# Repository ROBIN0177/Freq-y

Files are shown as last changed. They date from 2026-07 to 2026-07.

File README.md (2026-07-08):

# Freq-y
## Your Frequency Scanning Companion

I made this project because there isn't a cheap frequency scanner you can rely on. If you've built RF projects before, you know the pain of tracking down a signal leak, figuring out where it's coming from, what frequency it's on, and which device is causing it.

I ran into this myself: my home WiFi was getting choked by an unknown source. Turned out to be my own custom radio bleeding into the band. This scanner also lets you test how much shielding a material actually provides—whether it's a wall, a case, or a Faraday cage. Pinpoint the exact device causing interference easily. (Unlike me. Took 3 days to figure out..)

---

## Pictures




(Mind the hole, it's for a rocker switch I couldn't get a STL of.)





---

## BOM

Full BOM with DigiKey part numbers: see `/BOM/`

---

## File Structure

```
Freq-y/
├── CAD/
│   ├── enclosure_top.stl
│   └── enclosure_bottom.stl
├── PCB/
│   ├── Freq-y_Schem
|   ├── Freq-y_PCB
│   └── Freq-y_Pro
├── GERBER/
│   ├── Freq-y-B_Cu.gbr
│   ├── Freq-y-F_Cu.gbr
│   ├── Freq-y-B_Mask.gbr
│   ├── Freq-y-F_Mask.gbr
│   ├── Freq-y-B_Silkscreen.gbr
│   ├── Freq-y-F_Silkscreen.gbr
│   ├── Freq-y-Edge_Cuts.gbr
│   ├── Freq-y-B_Paste.gbr
│   ├── Freq-y-F_Paste.gbr
│   ├── Freq-y-NPTH.drl
│   ├── Freq-y-PTH.drl
│   └── Freq-y.zip
├── BOM/
│   ├── BOM_DigiKey.csv
│   └── BOM_AUX.csv
├── README.md
├── Journal.md
└── LICENSE
```

---

## Special Thanks

**Hack Club** — I couldn't have made this without it.

## NOTE

RF impedance was calculated to the nearest allowed mm. Any more would have severed and or created problems for other components!!
Range is limited due to it not having exact RF impedance!!

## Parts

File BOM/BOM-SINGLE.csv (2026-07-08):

Item | Description | Qty | Unit Price | Total | Vendor | Notes
 | === AMAZON PARTS (CAD → USD) ===
1 | SPST On/Off Mini Boat Rocker Switch, AC 6A/250V 10A/125V, 2 Solder Lug, 2Pin Toggle, Snap-in, 15 Pcs | 1 | $8.99 CAD → $6.47 USD | $8.99 CAD → $6.47 USD | ZUPAYIPA / Amazon.ca | In Stock
2 | Li-Po Battery Pack 3.7V 1100mAh 603449 with JST Connector | 1 | $17.85 CAD → $12.85 USD | $17.85 CAD → $12.85 USD | A2BATT INC / Amazon.ca | In Stock; verify device polarity before use
3 | Dual Band WiFi Antenna 2.4GHz/5GHz/5.8GHz MIMO, RP-SMA, Short | 1 | $13.99 CAD → $10.07 USD | $13.99 CAD → $10.07 USD | efagur / Amazon.ca | In Stock; for Furrion RV backup camera / router / repeater
4 | 2.8" 240x320 SPI ILI9341 LCD TFT Touch Panel, Serial Port | 1 | $23.23 CAD → $16.73 USD | $23.23 CAD → $16.73 USD | Ninlyier / Amazon.ca | Only 3 left in stock
 | Amazon Parts Subtotal |  | $64.06 CAD | $46.12 USD
 | Amazon Tax + Shipping |  | $9.54 USD | $9.54 USD
 | === OTHER SOURCES (USD) ===
 | PCB Fabrication (PCBWay) |  |  | $59.4 USD | PCB Vendor
 | Digi-Key Components |  |  | $45.32 USD | Digi-Key
 | === GRAND TOTAL (USD) === |  |  | $157.70999999999998 USD |  | Includes Amazon tax/shipping converted to USD

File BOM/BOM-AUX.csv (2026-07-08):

Item | Description | Qty | Unit Price | Total | Vendor | Notes
1 | SPST On/Off Mini Boat Rocker Switch, AC 6A/250V 10A/125V, 2 Solder Lug, 2Pin Toggle, Snap-in, 15 Pcs | 1 | 8.99 | 8.99 | ZUPAYIPA / Amazon.ca | In Stock
2 | Li-Po Battery Pack 3.7V 1100mAh 603449 with JST Connector | 1 | 17.85 | 17.85 | A2BATT INC / Amazon.ca | In Stock; verify device polarity before use
3 | Dual Band WiFi Antenna 2.4GHz/5GHz/5.8GHz MIMO, RP-SMA, Short | 1 | 13.99 | 13.99 | efagur / Amazon.ca | In Stock; for Furrion RV backup camera / router / repeater
4 | 2.8" 240x320 SPI ILI9341 LCD TFT Touch Panel, Serial Port | 1 | 23.23 | 23.23 | Ninlyier / Amazon.ca | Only 3 left in stock

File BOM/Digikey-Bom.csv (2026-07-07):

Index | Quantity | Part Number | Manufacturer Part Number | Description | Customer Reference | Available | Backorder | Unit Price | Extended Price CAD
1 | 10 | 1292-0603X106M100CT-ND | 0603X106M100CT | CAP CER 10UF 10V X5R 0603 |  | 10 | 0 | 0.06500 | 0.65
2 | 1 | 478-KGM15BR51A475MTCT-ND | 0603ZD475MAT2A | CAP CER 4.7?F 10V X5R 0603 |  | 1 | 0 | 1.04000 | 1.04
3 | 12 | 732-8013-1-ND | 885012206095 | CAP CER 0.1UF 50V X7R 0603 |  | 12 | 0 | 0.04500 | 0.54
4 | 4 | 490-1411-1-ND | GRM1885C1H220JA01D | CAP CER 22PF 50V C0G/NP0 0603 |  | 4 | 0 | 0.15000 | 0.60
5 | 4 | 490-16342-1-ND | GRM1885C1H1R0WA01D | CAP CER 1PF 50V C0G/NP0 0603 |  | 4 | 0 | 0.30000 | 1.20
6 | 1 | 732-5355-ND | 61301421021 | CONN HEADER R/A 14POS 2.54MM |  | 1 | 0 | 1.50000 | 1.50
7 | 1 | 490-7784-1-ND | LQM2MPN1R0NG0L | FIXED IND 1UH 1.4A 107 MOHM SMD |  | 1 | 0 | 0.26000 | 0.26
8 | 1 | 490-LQP03TG3N9B02DCT-ND | LQP03TG3N9B02D | FIXED IND 3.9NH 350MA 350 MOHM |  | 1 | 0 | 0.15000 | 0.15
9 | 1 | 2073-USB4105-GF-ACT-ND | USB4105-GF-A | CONN RCP USB2.0 TYP C 16P SMD RA |  | 1 | 0 | 1.20000 | 1.20
10 | 1 | 311-5.10KHRCT-ND | RC0603FR-075K1L | RES 5.1K OHM 1% 1/10W 0603 |  | 1 | 0 | 0.16000 | 0.16
11 | 1 | 311-2.00KHRCT-ND | RC0603FR-072KL | RES 2K OHM 1% 1/10W 0603 |  | 1 | 0 | 0.16000 | 0.16
12 | 1 | 311-10.0KHRCT-ND | RC0603FR-0710KL | RES 10K OHM 1% 1/10W 0603 |  | 1 | 0 | 0.16000 | 0.16
13 | 1 | 311-22.0KHRCT-ND | RC0603FR-0722KL | RES 22K OHM 1% 1/10W 0603 |  | 1 | 0 | 0.16000 | 0.16
14 | 1 | 311-56KHRCT-ND | RC0603FR-0756KL | RES 56K OHM 1% 1/10W 0603 |  | 1 | 0 | 0.16000 | 0.16
15 | 2 | 311-4.70KHRCT-ND | RC0603FR-074K7L | RES 4.7K OHM 1% 1/10W 0603 |  | 2 | 0 | 0.16000 | 0.32
16 | 1 | EG1903-ND | EG1218 | SWITCH SLIDE SPDT 200MA 30V |  | 1 | 0 | 1.08000 | 1.08
17 | 1 | 296-35718-1-ND | CC1101RGPR | IC RF TXRX ISM<1GHZ 20QFN |  | 1 | 0 | 6.46000 | 6.46
18 | 1 | 5407-ESP32-S3-MINI-1-N8CT-ND | ESP32-S3-MINI-1-N8 | RF TXRX MODULE BT PCB TRACE SMD |  | 1 | 0 | 8.68000 | 8.68
19 | 1 | MAX17048G+T10CT-ND | MAX17048G+T10 | IC BATT MON LI-ION 1CELL 8TDFN |  | 1 | 0 | 6.75000 | 6.75
20 | 1 | MCP73831T-2ACI/OTCT-ND | MCP73831T-2ACI/OT | IC BATT CNTL LI-ION 1CEL SOT23-5 |  | 1 | 0 | 1.22000 | 1.22
21 | 2 | 535-9134-1-ND | ABM8-16.000MHZ-B2-T | CRYSTAL 16.0000MHZ 18PF SMD |  | 2 | 0 | 0.83000 | 1.66
22 | 2 | 644-STDCSQ1-26MCT-ND | STDCSQ1-26M | CRYSTAL 26.0000MHZ 10PF SMD |  | 2 | 0 | 1.44000 | 2.88
23 | 1 | 4823-NRF24L01P-R7CT-ND | NRF24L01P-R7 | IC RF TXRX ISM>1GHZ 20QFN |  | 1 | 0 | 6.81000 | 6.81
24 | 2 | 357-CON-SMA-EDGE-ND | CON-SMA-EDGE | CIRCULAR COAXIAL SUB-MINITURE |  | 2 | 0 | 3.35000 | 6.70
25 | 1 | 296-12719-1-ND | TPS62203DBVT | IC REG BUCK 3.3V 300MA SOT23-5 |  | 1 | 0 | 2.88000 | 2.88
26 | 2 | 490-14914-1-ND | LQP03TQ12NH02D | FIXED IND 12NH 250MA 690 MOHM |  | 2 | 0 | 0.16000 | 0.32
27 | 2 | 490-6716-1-ND | LQP03TN1N2B02D | FIXED IND 1.2NH 750MA 100 MOHM |  | 2 | 0 | 0.15000 | 0.30

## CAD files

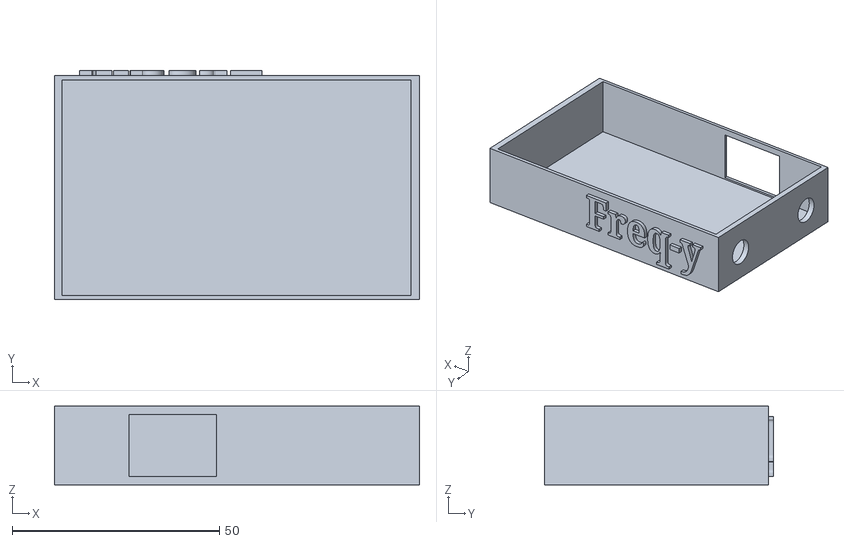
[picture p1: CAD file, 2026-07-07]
CAD/enclosure-bottom.stl
88.0 x 55.2 x 19.0

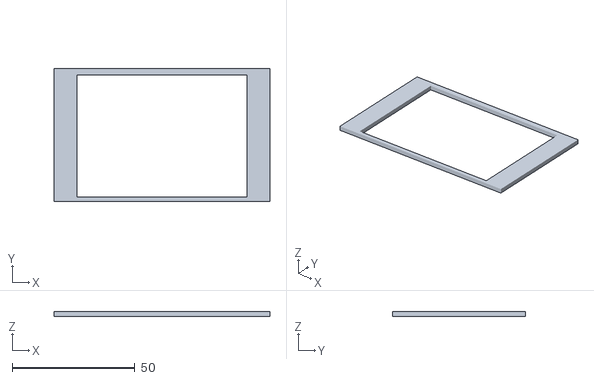
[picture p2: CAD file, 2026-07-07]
CAD/enclosure-top.stl
88.0 x 54.0 x 2.00

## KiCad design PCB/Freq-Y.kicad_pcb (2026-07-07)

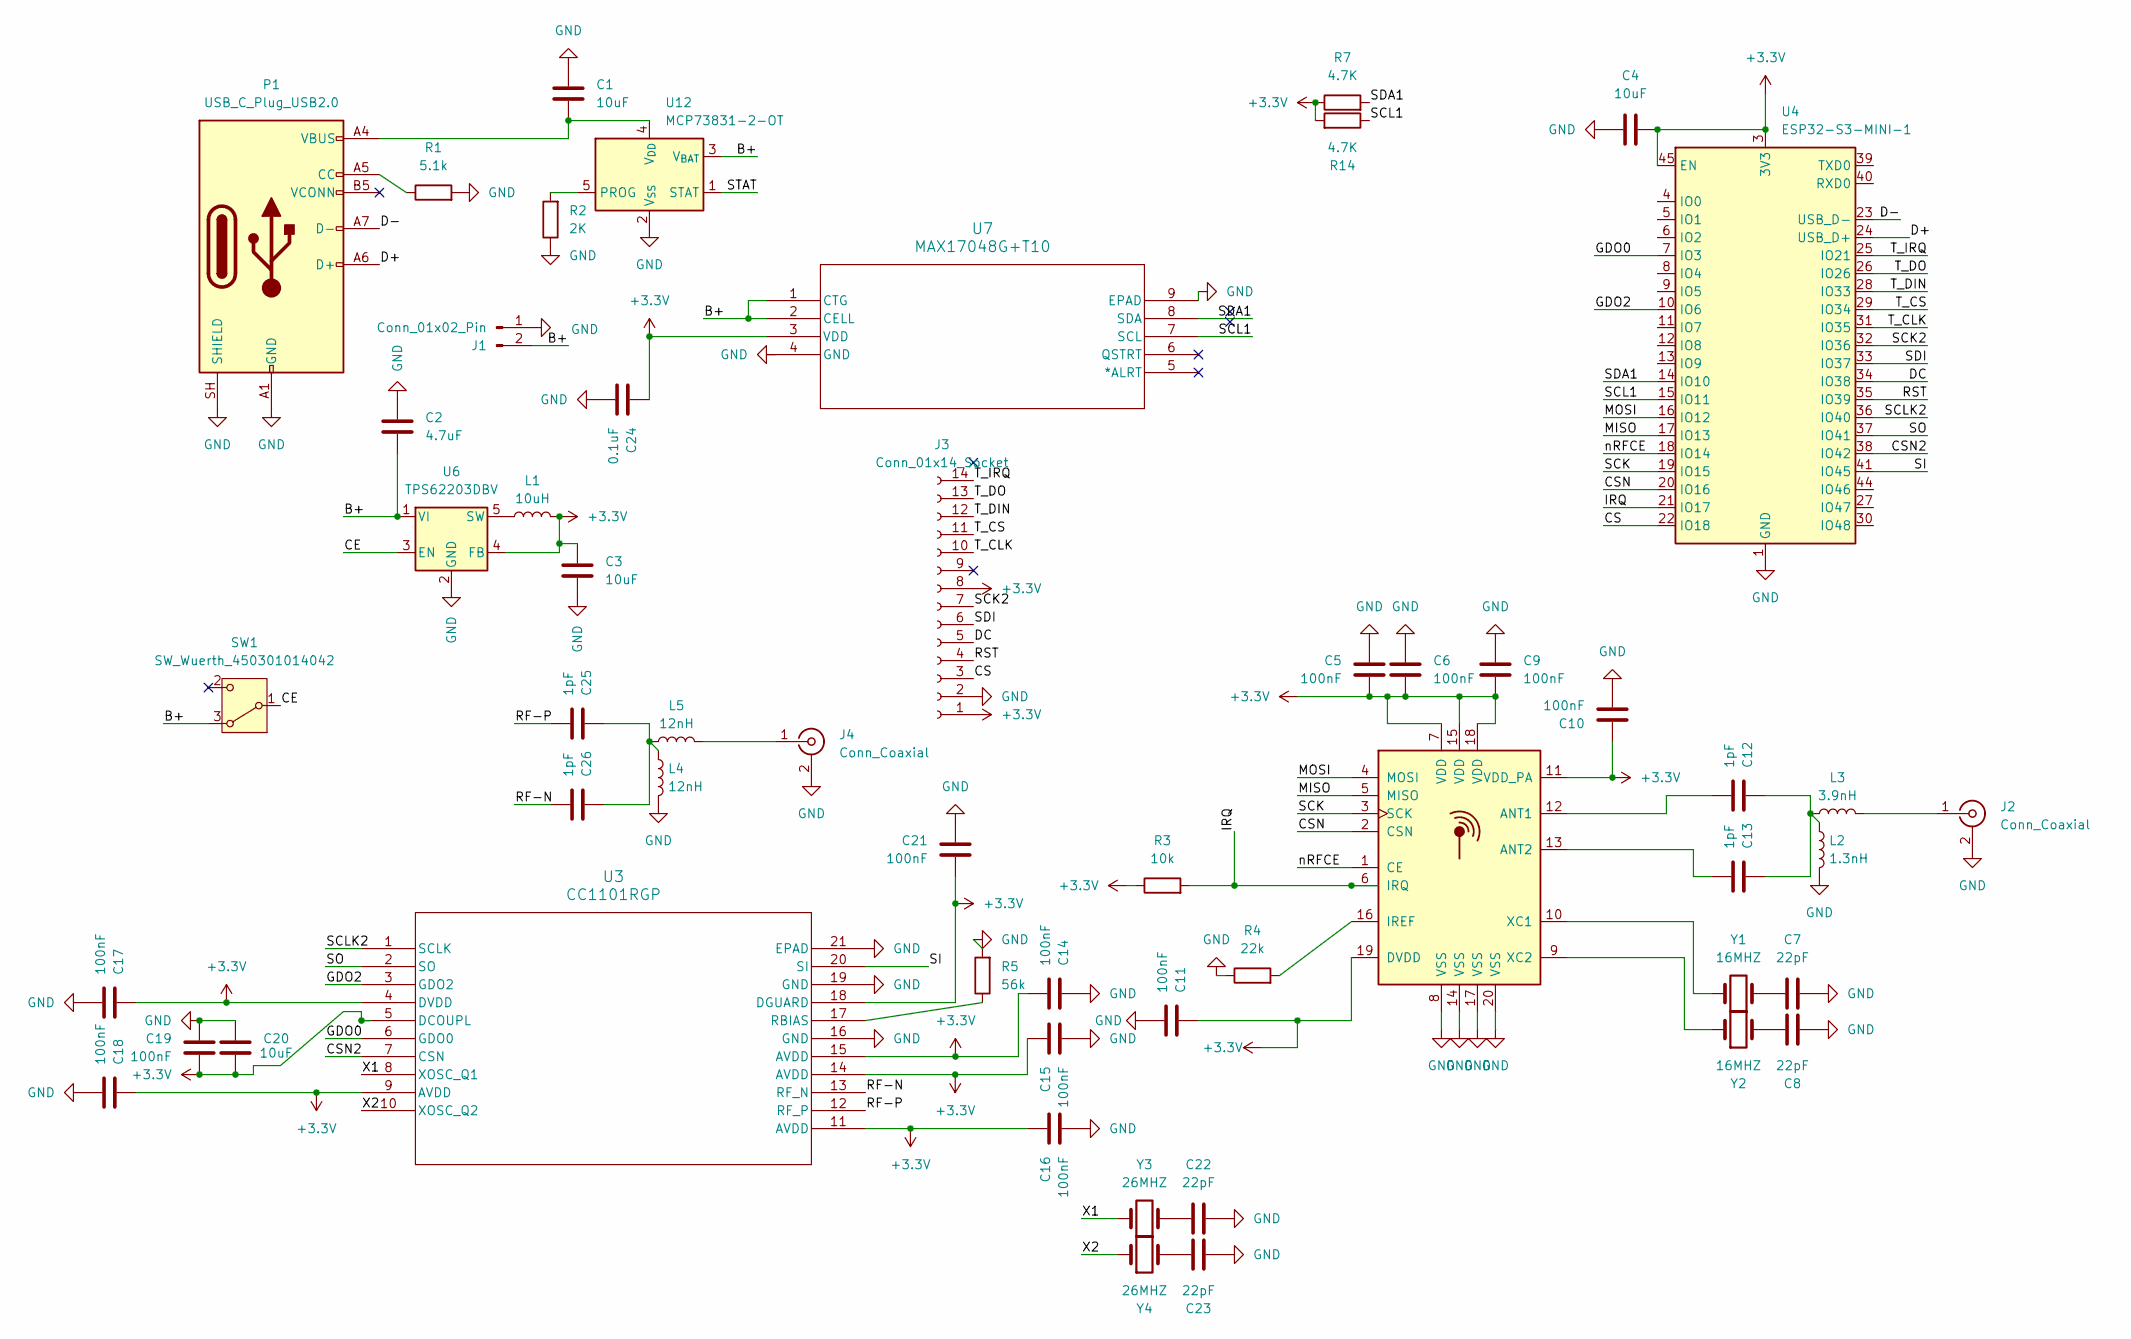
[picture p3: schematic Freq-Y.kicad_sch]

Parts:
C1, C3, C4, C20: 10uF; C_0603_1608Metric
C2: 4.7uF; C_0603_1608Metric
C5, C6, C9, C10, C11, C14, C15, C16, C17, C18, C19, C21: 100nF; C_0603_1608Metric
C7, C8, C22, C23: 22pF; C_0603_1608Metric
C12, C13, C25, C26: 1pF; C_0603_1608Metric
C24: 0.1uF; C_0603_1608Metric
J1: Conn_01x02_Pin; PinSocket_1x02_P1.00mm_Vertical
J2, J4: Conn_Coaxial; SMA_Molex_73251-1153_EdgeMount_Horizontal
J3: Conn_01x14_Socket; PinSocket_1x14_P2.54mm_Vertical
L1: 10uH; L_0805_2012Metric
L2: 1.3nH; L_0805_2012Metric
L3: 3.9nH; L_0805_2012Metric
L4, L5: 12nH; L_0805_2012Metric
P1: USB_C_Plug_USB2.0; USB_C_Receptacle_GCT_USB4105-xx-A_16P_TopMnt_Horizontal
R1: 5.1k; R_0603_1608Metric
R2: 2K; R_0603_1608Metric
R3: 10k; R_0603_1608Metric
R4: 22k; R_0603_1608Metric
R5: 56k; R_0603_1608Metric
R7, R14: 4.7K; R_0603_1608Metric
SW1: SW_Wuerth_450301014042; SW_Slide-03_Wuerth-WS-SLTV_10x2.5x6.4_P2.54mm
U2: nRF24L01P; QFN-20-1EP_4x4mm_P0.5mm_EP2.5x2.5mm
U3: CC1101RGP; RGP20_2P4X2P4
U4: ESP32-S3-MINI-1; ESP32-S2-MINI-1
U6: TPS62203DBV; SOT-23-5
U7: MAX17048G+T10; 21-0168E_T822-3_MXM
U12: MCP73831-2-OT; SOT-23-5
Y1, Y2: 16MHZ; Crystal_SMD_0603-2Pin_6.0x3.5mm
Y3, Y4: 26MHZ; Crystal_SMD_0603-2Pin_6.0x3.5mm

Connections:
+3.3V: C3.1, C4.2, C5.2, C6.2, C9.2, C10.1, C11.1, C14.2, C15.1, C16.1, C17.1, C18.1, C19.2, C20.2, C21.2, C24.1, J3.1, J3.8, L1.2, R3.1, R7.1, R14.2, U2.7 (VDD), U2.11 (VDD_PA), U2.15 (VDD), U2.18 (VDD), U2.19 (DVDD), U3.4 (DVDD), U3.5 (DCOUPL), U3.9 (AVDD), U3.11 (AVDD), U3.14 (AVDD), U3.15 (AVDD), U3.18 (DGUARD), U4.3 (3V3), U4.45 (EN), U6.4 (FB), U7.3 (VDD)
/B+: C2.1, J1.2, SW1.3 (A), U6.1 (VI), U7.1 (CTG), U7.2 (CELL), U12.3 (V_{BAT})
/CE: SW1.1 (B), U6.3 (EN)
/CS: J3.3, U4.22 (IO18)
/CSN: U2.2 (CSN), U4.20 (IO16)
/CSN2: U3.7 (CSN), U4.38 (IO42)
/D+: P1.A6 (D+), U4.24 (USB_D+)
/D-: P1.A7 (D-), U4.23 (USB_D-)
/DC: J3.5, U4.34 (IO38)
/GDO0: U3.6 (GDO0), U4.7 (IO3)
/GDO2: U3.3 (GDO2), U4.10 (IO6)
/IRQ: R3.2, U2.6 (IRQ), U4.21 (IO17)
/MISO: U2.5 (MISO), U4.17 (IO13)
/MOSI: U2.4 (MOSI), U4.16 (IO12)
/RF-N: C26.2, U3.13 (RF_N)
/RF-P: C25.2, U3.12 (RF_P)
/RST: J3.4, U4.35 (IO39)
/SCK: U2.3 (SCK), U4.19 (IO15)
/SCK2: J3.7, U4.32 (IO36)
/SCL1: R14.1, U4.15 (IO11), U7.7 (SCL)
/SCLK2: U3.1 (SCLK), U4.36 (IO40)
/SDA1: R7.2, U4.14 (IO10), U7.8 (SDA)
/SDI: J3.6, U4.33 (IO37)
/SI: U3.20 (SI), U4.41 (IO45)
/SO: U3.2 (SO), U4.37 (IO41)
/STAT: U12.1 (STAT)
/T_CLK: J3.10, U4.31 (IO35)
/T_CS: J3.11, U4.29 (IO34)
/T_DIN: J3.12, U4.28 (IO33)
/T_DO: J3.13, U4.26 (IO26)
/T_IRQ: J3.14, U4.25 (IO21)
/X1: U3.8 (XOSC_Q1), Y3.2
/X2: U3.10 (XOSC_Q2), Y4.1
/nRFCE: U2.1 (CE), U4.18 (IO14)
GND: C1.1, C2.2, C3.2, C4.1, C5.1, C6.1, C7.2, C8.1, C9.1, C10.2, C11.2, C14.1, C15.2, C16.2, C17.2, C18.2, C19.1, C20.1, C21.1, C22.2, C23.1, C24.2, J1.1, J2.2 (Ext), J3.2, J4.2 (Ext), L2.2, L4.2, P1.A1 (GND), P1.A12 (GND), P1.B1 (GND), P1.B12 (GND), P1.SH (SHIELD), R1.2, R2.1, R4.1, R5.2, U2.8 (VSS), U2.14 (VSS), U2.17 (VSS), U2.20 (VSS), U3.16 (GND), U3.19 (GND), U3.21 (EPAD), U4.1 (GND), U4.2 (GND), U4.42 (GND), U4.43 (GND), U4.46 (GND), U4.47 (GND), U4.48 (GND), U4.49 (GND), U4.50 (GND), U4.51 (GND), U4.52 (GND), U4.53 (GND), U4.54 (GND), U4.55 (GND), U4.56 (GND), U4.57 (GND), U4.58 (GND), U4.59 (GND), U4.60 (GND), U4.61 (GND), U4.62 (GND), U4.63 (GND), U4.64 (GND), U4.65 (GND), U6.2 (GND), U7.9 (EPAD), U12.2 (V_{SS})
unnamed: C7.1, Y1.1
unnamed: C8.2, Y2.2
unnamed: C12.1, C13.1, L2.1, L3.1
unnamed: C22.1, Y3.1
unnamed: C23.2, Y4.2
unnamed: C25.1, C26.1, L4.1, L5.1
unnamed: J2.1 (In), L3.2
unnamed: J4.1 (In), L5.2
unnamed: P1.A5 (CC), R1.1
unnamed: C12.2, U2.12 (ANT1)
unnamed: C13.2, U2.13 (ANT2)
unnamed: R4.2, U2.16 (IREF)
unnamed: U2.10 (XC1), Y1.2
unnamed: U2.9 (XC2), Y2.1
unnamed: R5.1, U3.17 (RBIAS)
unnamed: L1.1, U6.5 (SW)
unnamed: R2.2, U12.5 (PROG)
unnamed: C1.2, P1.A4 (VBUS), P1.A9 (VBUS), P1.B4 (VBUS), P1.B9 (VBUS), U12.4 (V_{DD})

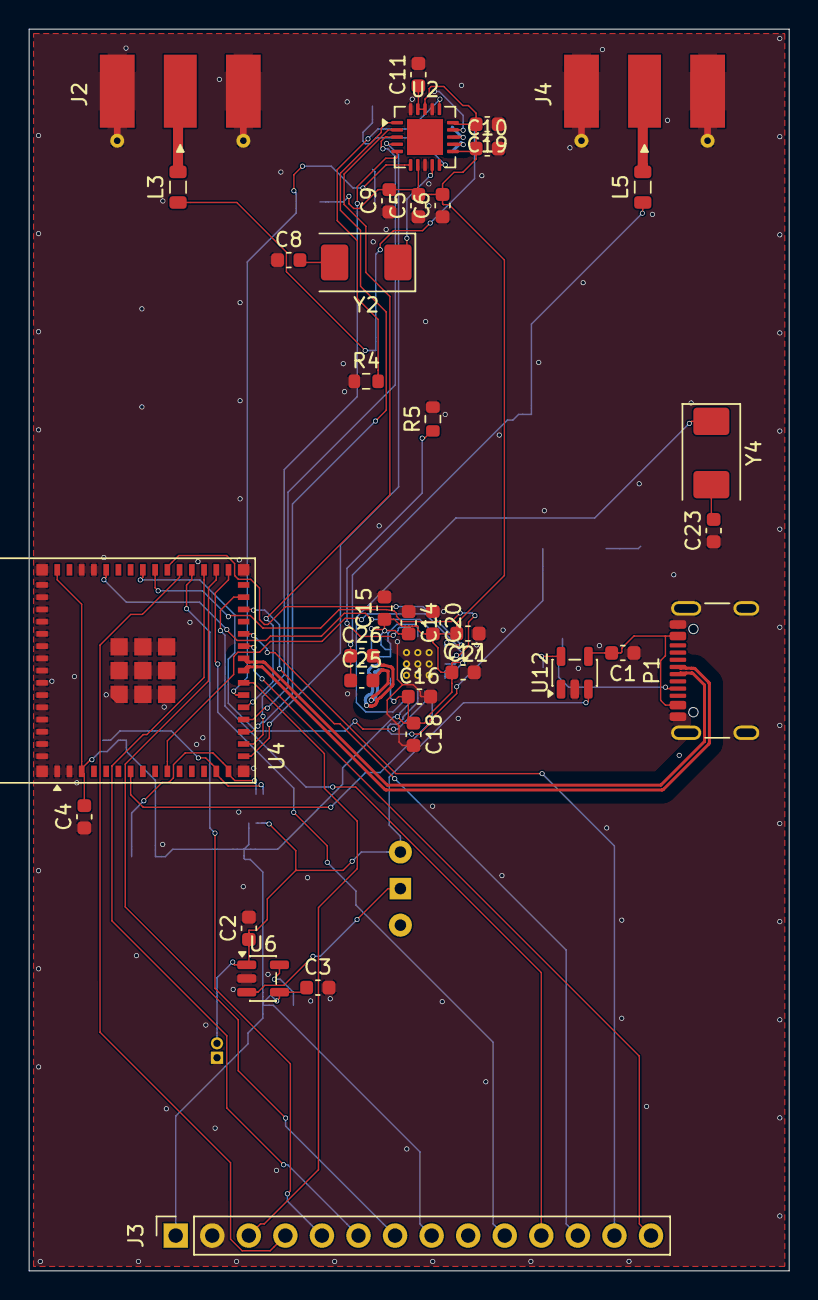
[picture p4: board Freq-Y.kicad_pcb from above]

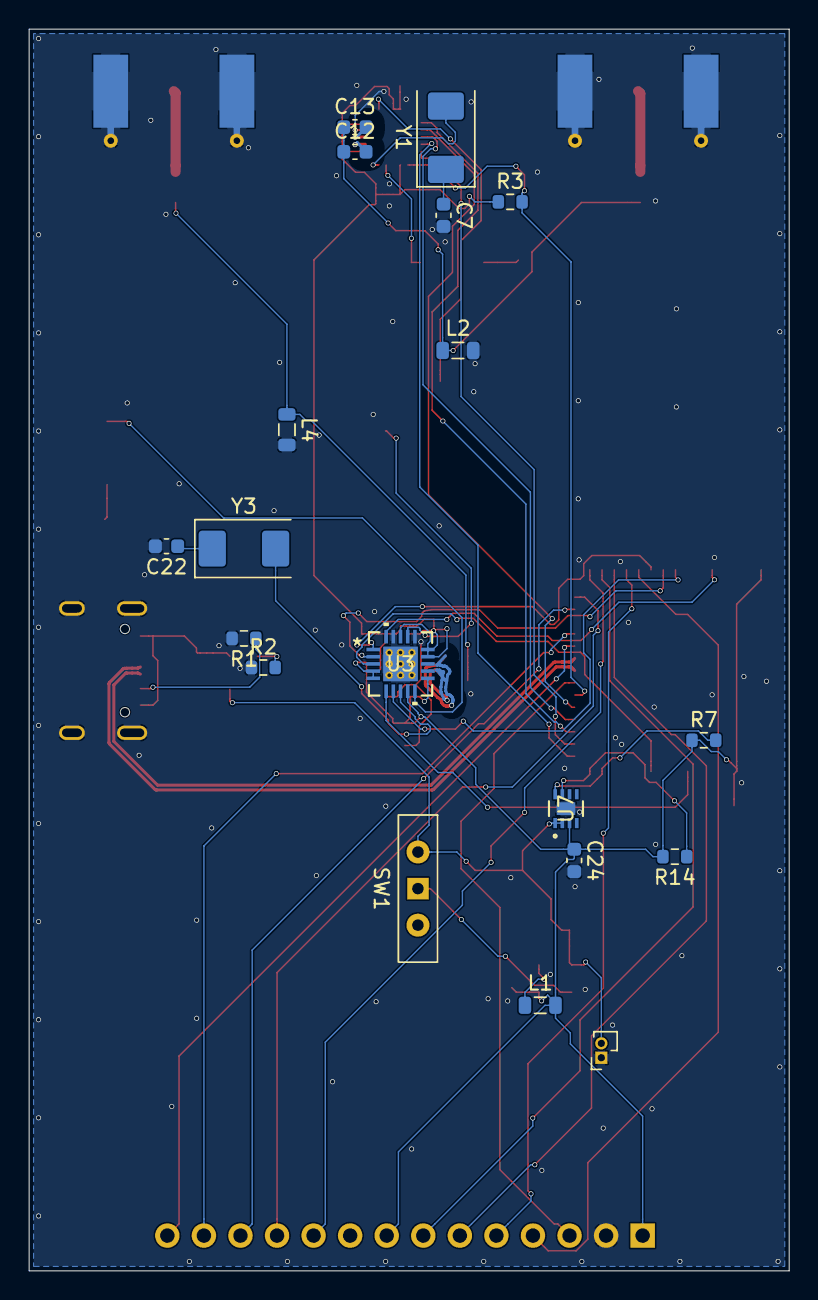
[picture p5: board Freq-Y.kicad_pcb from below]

Board: 2 copper layers, 52.8 x 86.3 mm, 54 parts (19 on the bottom side), 52 nets.

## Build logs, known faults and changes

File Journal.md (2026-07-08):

# RF Signal Scanner — Build Journal

*Third project so far. Not super comfortable with advanced calculations yet, but here we are.*

---

## DEVLOG 1 - Component Selection & Datasheet Review

Opened KiCad and laid out all the major components: TPS4056, USB-C, nRF24L01+, CC1101, and supporting passives. Read through every datasheet and took notes for this project's requirements.

(changed some chips due to availability)
**Time: 2.3 hrs**

---

## DEVLOG 2 — Schematic

Schematic work was straightforward. Main challenge was real estate, I was missing space,  bumped the page size and got too much dead space, kept it tight and had to cram things in. Settled with smaller size.


**Time: 4.1 hrs**

---

## DEVLOG 3 —  Case Design

Decided to nail the case dimensions before locking the PCB size. Sourced the display on Amazon, settled on 6 mm side bezels for clean proportions, thick enough to look intentional, thin enough to stay stable. Added walls, cutouts, etc.


**Time: 1.2 hrs**

---

## DEVLOG 4 — PCB Layout & Routing

With the Case fixed, routed the board. Grouped RF components tight to keep traces short. Trace widths aren't textbook RF-grade, but the target range is ~3 m radius so the margin holds. Layout iterations took a while finding the right component placement was a PAIN.


**Time: 8.7 hrs**

---

## DEVLOG 5 — Renders

Exported the STL into Blender for final shots. Lighting setup got weird, a red shadow artifact kept showing up no matter what. Couldn't track it down, but the renders still came out clean. Project looks sigma.


**Time: 2.0 hrs**

---

### TOTAL TIME: 18.3 HOURS

(plz approve, lolol)

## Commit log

2026-07-07 Enhance README with project information and visuals
    Expanded the README with project details, images, BOM, file structure, and acknowledgments.
2026-07-08 Revise Journal.md with new devlog entries
    Updated journal entries with detailed notes on component selection, schematic design, case dimensions, PCB layout, and rendering process.
